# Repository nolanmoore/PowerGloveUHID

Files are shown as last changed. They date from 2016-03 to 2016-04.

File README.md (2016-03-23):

## Intro

In a world... where wires are a thing of the past, pound signs are now hashtags and there is always a “new black,” one man will revive a gaming icon in order to preserve the past… and control the future.

The ultimate goal of the Power Glove UHID (Universal Human Interface Device) project is to revamp the 1989 Nintendo Power Glove with modern sensors, giving you the ability to use gesture controls with almost anything you can think of, in style.

Check out the [Hackaday.io project page](https://hackaday.io/project/8455-power-glove-uhid) for more info!

## Revisions

### Main Board
* Rev 0.1 (current): Complete! Features custom keypad, Teensy 3/LC header, ESP-12E/01 headers and Pololu 3.3V step up/down regulator.<br />
Top side:<br />
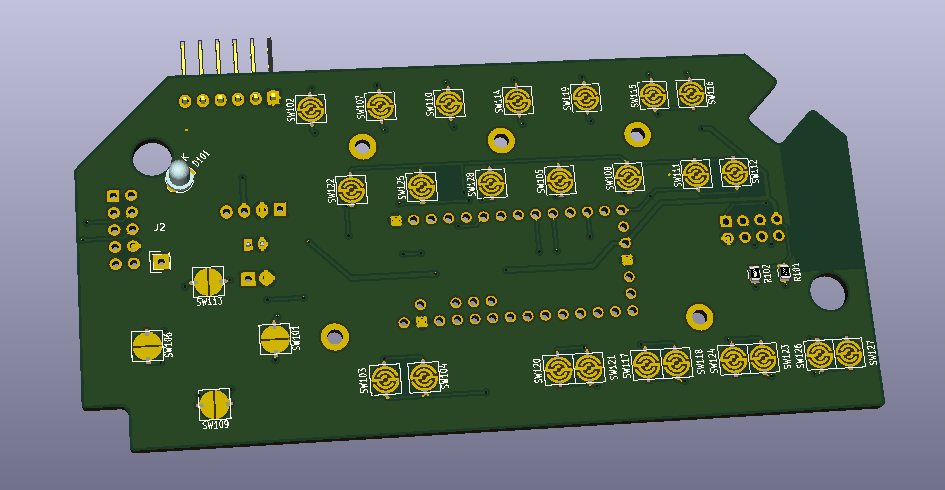
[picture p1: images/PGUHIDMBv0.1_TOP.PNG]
Power Glove UHID main board - top side
<br />
Bottom side:<br />
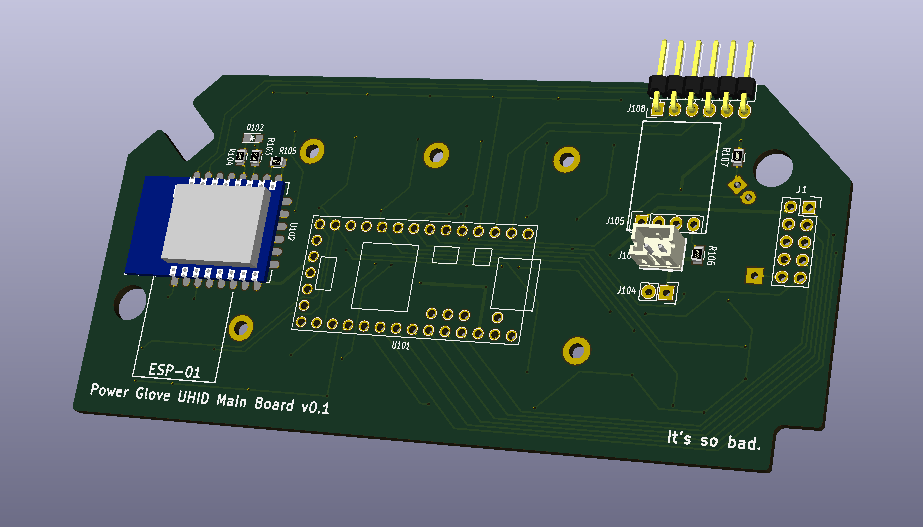
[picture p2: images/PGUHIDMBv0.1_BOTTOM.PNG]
Power Glove UHID main board - bottom side


### Sensor Board
* Rev 0.1 (current): Unfinished WIP. Along with the existing flex sensors, the current prototype sensor board will feature a Pololu AltIMU-10 as the main sensor.

## License

This is an open hardware design licensed under the terms of the CERN Open Hardware Licence (OHL) v1.2.

You may redistribute and modify this documentation under the terms of the CERN OHL v.1.2 (http://ohwr.org/cernohl). This documentation is distributed WITHOUT ANY EXPRESS OR IMPLIED WARRANTY, INCLUDING OF MERCHANTABILITY, SATISFACTORY QUALITY AND FITNESS FOR A PARTICULAR PURPOSE. Please see the CERN OHL v.1.2 for applicable conditions.

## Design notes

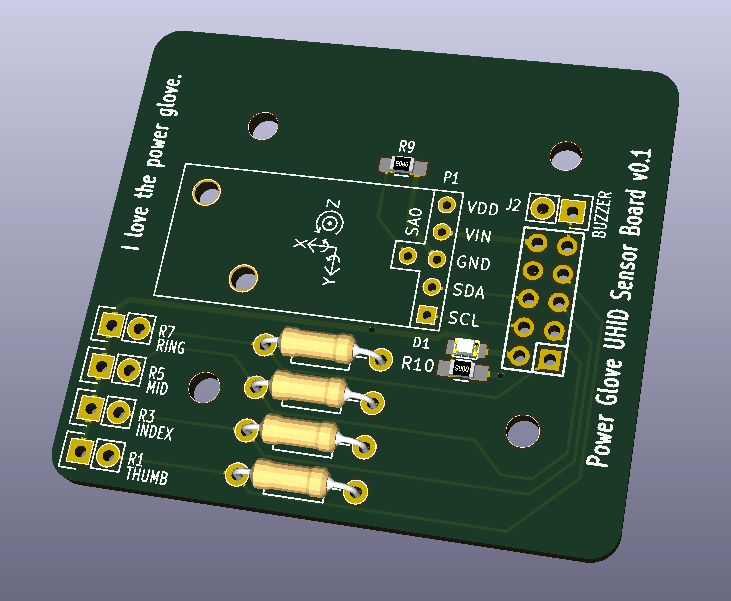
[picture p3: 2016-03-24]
images/PGUHIDSBv0.1_TOP.PNG

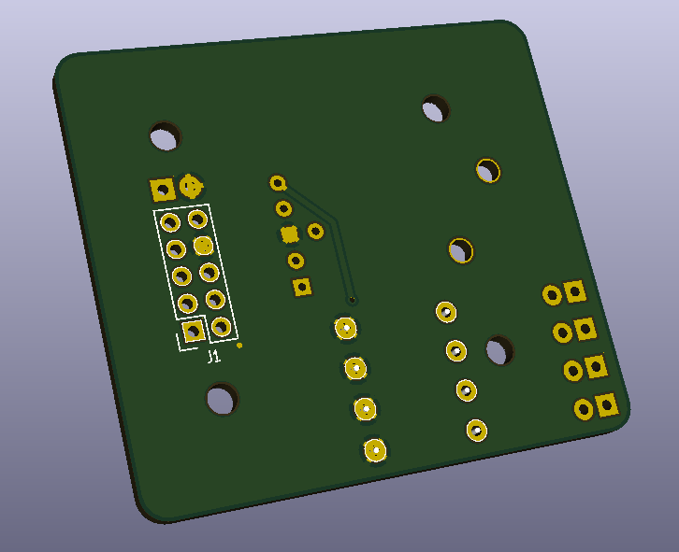
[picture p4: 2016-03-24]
images/PGUHIDSBv0.1_BOTTOM.PNG

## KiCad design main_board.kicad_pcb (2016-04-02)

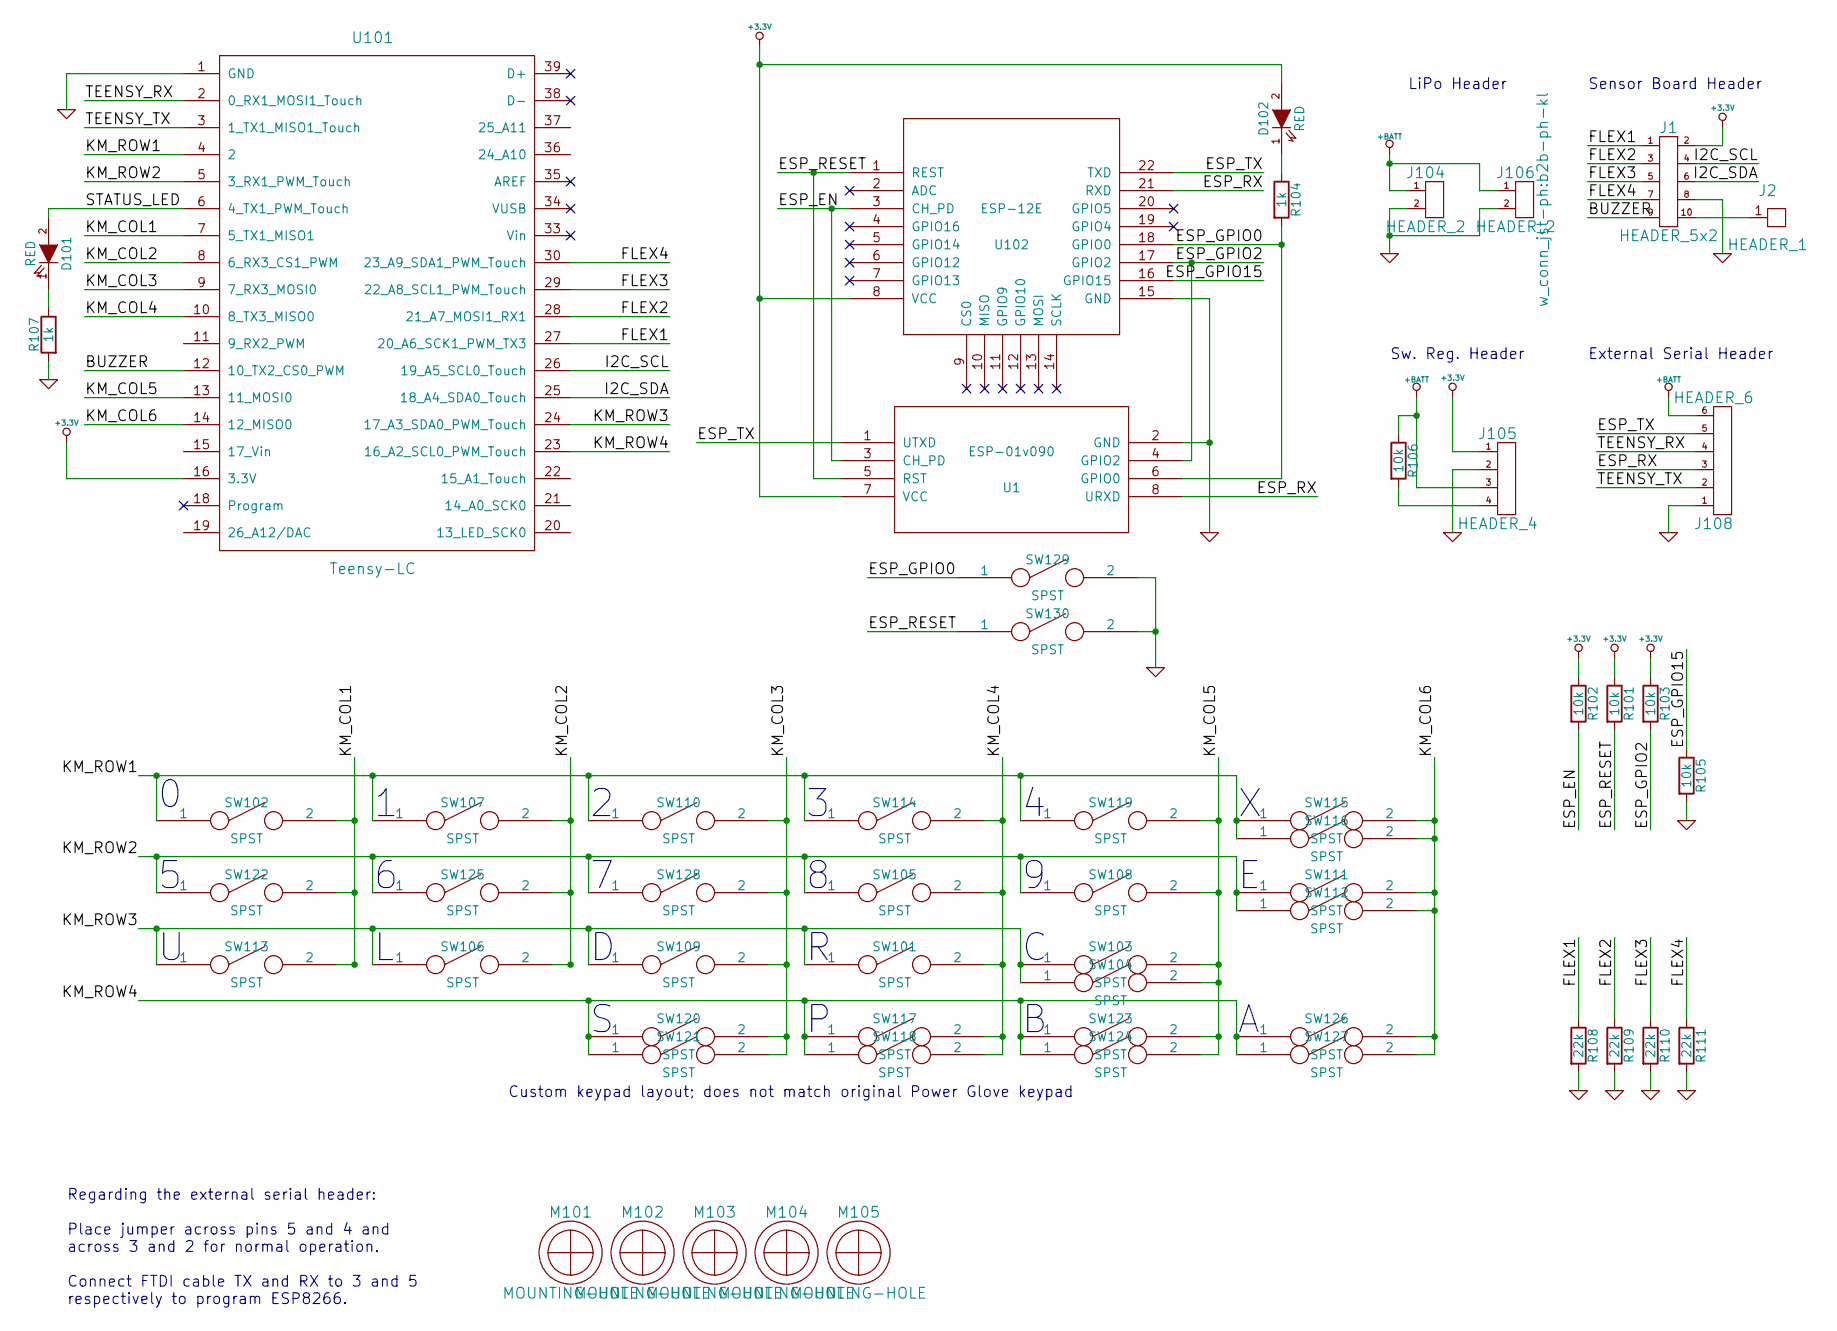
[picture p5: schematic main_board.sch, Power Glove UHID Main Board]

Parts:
D101: RED; LED-3MM
D102: RED; LED_0805
J1: HEADER_5x2; Socket_Strip_Straight_2x05
J2: HEADER_1; Socket_Strip_Straight_1x01
J104: HEADER_2; Socket_Strip_Straight_1x02
J105: HEADER_4; Socket_Strip_Straight_1x04
J106: HEADER_2; b2b-ph-kl
J108: HEADER_6; Pin_Header_Angled_1x06
M101, M102, M103, M104, M105: MOUNTING-HOLE; MountingHole_2-2mm
R101, R102, R103, R105, R106: 10k; R_0805
R104, R107: 1k; R_0805
R108, R109, R110, R111: 22k; R_0805
SW101, SW106, SW109, SW113: SPST; CONDUCTIVE-PAD-HALFSHELL-150MIL
SW102, SW103, SW104, SW105, SW107, SW108, SW110, SW111, SW112, SW114, SW115, SW116, SW117, SW118, SW119, SW120, SW121, SW122, SW123, SW124, SW125, SW126, SW127, SW128: SPST; CONDUCTIVE-PAD-STANDARD-150MIL
SW129, SW130: SPST; Socket_Strip_Straight_1x02
U1: ESP-01v090; ESP-01
U101: Teensy-LC; Teensy3.x_LC
U102: ESP-12E

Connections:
+3.3V: D102.2 (A), J1.2, J105.1, R101.1, R102.1, R103.1, U1.7 (VCC), U101.16 (3.3V), U101.31 (3.3V), U102.8 (VCC)
+BATT: J104.1, J105.3, J106.1, J108.6, R106.1
/BUZZER: J1.9, U101.12 (10_TX2_CS0_PWM)
/ESP_EN: R102.2, U1.3 (CH_PD), U102.3 (CH_PD)
/ESP_GPIO0: R104.2, SW129.1, U1.6 (GPIO0), U102.18 (GPIO0)
/ESP_GPIO2: R103.2, U1.4 (GPIO2), U102.17 (GPIO2)
/ESP_GPIO15: R105.1, U102.16 (GPIO15)
/ESP_RESET: R101.2, SW130.1, U1.5 (RST), U102.1 (REST)
/ESP_RX: J108.3, U1.8 (URXD), U102.21 (RXD)
/ESP_TX: J108.5, U1.1 (UTXD), U102.22 (TXD)
/FLEX1: J1.1, R108.1, U101.27 (20_A6_SCK1_PWM_TX3)
/FLEX2: J1.3, R109.1, U101.28 (21_A7_MOSI1_RX1)
/FLEX3: J1.5, R110.1, U101.29 (22_A8_SCL1_PWM_Touch)
/FLEX4: J1.7, R111.1, U101.30 (23_A9_SDA1_PWM_Touch)
/I2C_SCL: J1.4, U101.26 (19_A5_SCL0_Touch)
/I2C_SDA: J1.6, U101.25 (18_A4_SDA0_Touch)
/KM_COL1: SW102.2, SW113.2, SW122.2, U101.7 (5_TX1_MISO1)
/KM_COL2: SW106.2, SW107.2, SW125.2, U101.8 (6_RX3_CS1_PWM)
/KM_COL3: SW109.2, SW110.2, SW120.2, SW121.2, SW128.2, U101.9 (7_RX3_MOSI0)
/KM_COL4: SW101.2, SW105.2, SW114.2, SW117.2, SW118.2, U101.10 (8_TX3_MISO0)
/KM_COL5: SW103.2, SW104.2, SW108.2, SW119.2, SW123.2, SW124.2, U101.13 (11_MOSI0)
/KM_COL6: SW111.2, SW112.2, SW115.2, SW116.2, SW126.2, SW127.2, U101.14 (12_MISO0)
/KM_ROW1: SW102.1, SW107.1, SW110.1, SW114.1, SW115.1, SW116.1, SW119.1, U101.4 (2)
/KM_ROW2: SW105.1, SW108.1, SW111.1, SW112.1, SW122.1, SW125.1, SW128.1, U101.5 (3_RX1_PWM_Touch)
/KM_ROW3: SW101.1, SW103.1, SW104.1, SW106.1, SW109.1, SW113.1, U101.24 (17_A3_SDA0_PWM_Touch)
/KM_ROW4: SW117.1, SW118.1, SW120.1, SW121.1, SW123.1, SW124.1, SW126.1, SW127.1, U101.23 (16_A2_SCL0_PWM_Touch)
/STATUS_LED: D101.2 (A), U101.6 (4_TX1_PWM_Touch)
/TEENSY_RX: J108.4, U101.2 (0_RX1_MOSI1_Touch)
/TEENSY_TX: J108.2, U101.3 (1_TX1_MISO1_Touch)
GND: J1.8, J104.2, J105.2, J106.2, J108.1, R105.2, R107.2, R108.2, R109.2, R110.2, R111.2, SW129.2, SW130.2, U1.2 (GND), U101.1 (GND), U101.17 (GND), U101.32 (GND), U102.15 (GND)
unnamed: D101.1 (K), R107.1
unnamed: D102.1 (K), R104.1
unnamed: J1.10, J2.1
unnamed: J105.4, R106.2

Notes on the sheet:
Sensor Board Header
LiPo Header
Custom keypad layout; does not match original Power Glove keypad
External Serial Header
Regarding the external serial header: Place jumper across pins 5 and 4 and across 3 and 2 for normal operation. Connect FTDI cable TX and RX to 3 and 5 respectively to program ESP8266.
Sw. Reg. Header

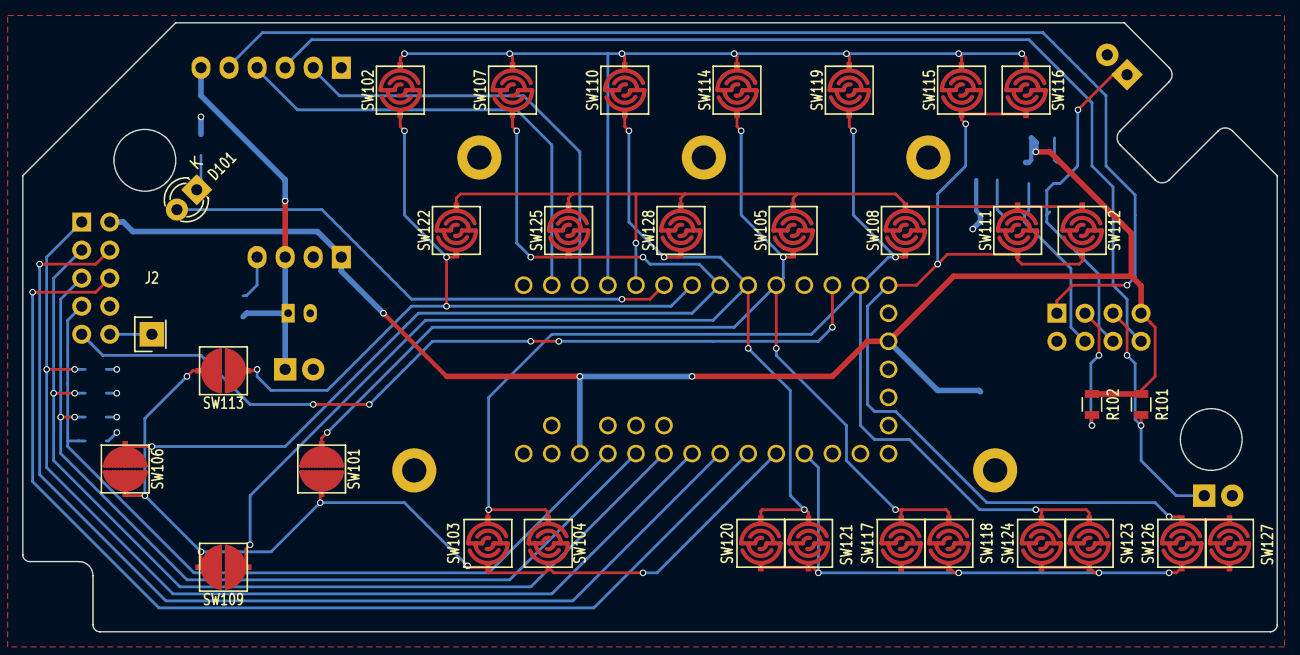
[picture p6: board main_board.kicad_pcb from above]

Board: 2 copper layers, 113.5 x 55.1 mm, 57 parts (0 on the bottom side), 34 nets.

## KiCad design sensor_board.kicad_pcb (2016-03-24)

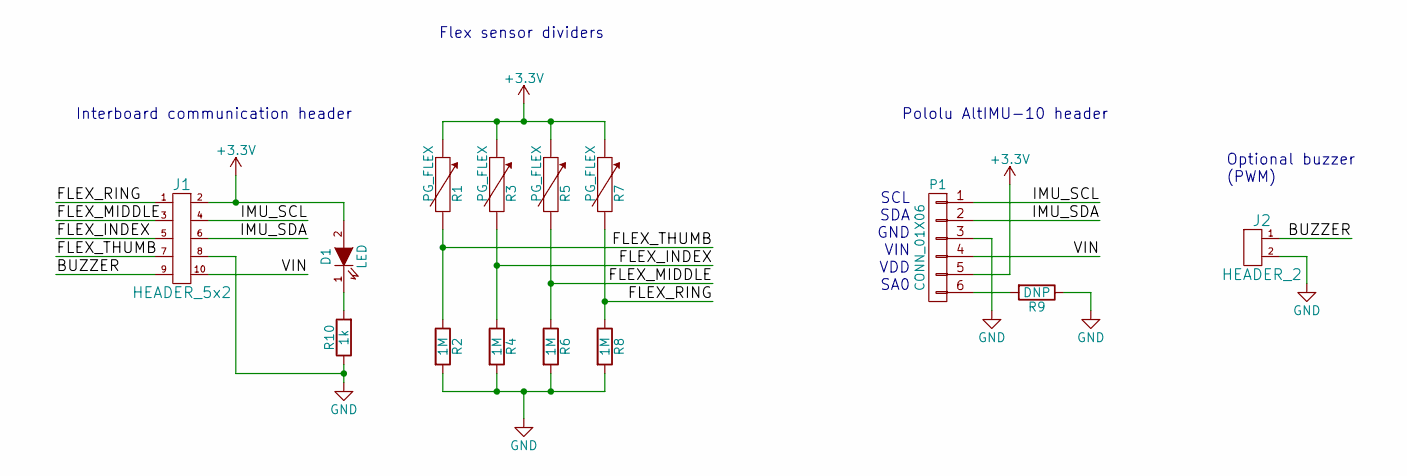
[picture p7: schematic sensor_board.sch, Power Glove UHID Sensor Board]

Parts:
D1: LED; Led_0805
J1: HEADER_5x2; Socket_Strip_Straight_2x05
J2: HEADER_2; Socket_Strip_Straight_1x02
P1: CONN_01X06; ALTIMU10
R1, R3, R5, R7: PG_FLEX; Socket_Strip_Straight_1x02
R2, R4, R6, R8: 1M; Resistor_Horizontal_RM10mm
R9: DNP; R_0805_HandSoldering
R10: 1k; R_0805_HandSoldering

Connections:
+3V3: D1.2 (A), J1.2, P1.5, R1.1, R3.1, R5.1, R7.1
/BUZZER: J1.9, J2.1
/FLEX_INDEX: J1.5, R3.2, R4.1
/FLEX_MIDDLE: J1.3, R5.2, R6.1
/FLEX_RING: J1.1, R7.2, R8.1
/FLEX_THUMB: J1.7, R1.2, R2.1
/IMU_SCL: J1.4, P1.1
/IMU_SDA: J1.6, P1.2
/VIN: J1.10, P1.4
GND: J1.8, J2.2, P1.3, R2.2, R4.2, R6.2, R8.2, R9.1, R10.1
unnamed: D1.1 (K), R10.2
unnamed: P1.6, R9.2

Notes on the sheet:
SCL SDA GND VIN VDD SA0
Flex sensor dividers
Interboard communication header
Pololu AltIMU-10 header
Optional buzzer (PWM)

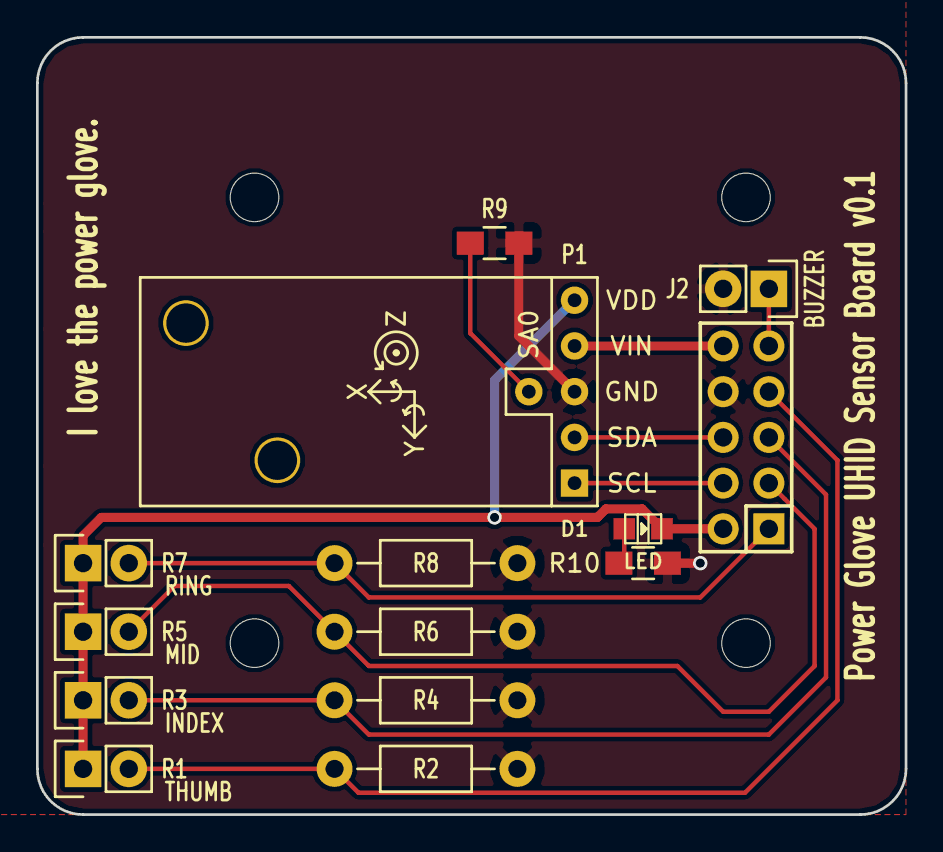
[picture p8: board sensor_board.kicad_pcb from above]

Board: 2 copper layers, 48.3 x 43.2 mm, 14 parts (1 on the bottom side), 12 nets.

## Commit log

2016-03-13 Initial upload, everything still WIP
    I do NOT advise you to send these to OSH just yet
    [main_board.kicad_pcb, main_board.sch, sensor_board.kicad_pcb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]
2016-03-21 Final main board v0.1
    Last big upload commit before I start doing proper commits ;)
    [main_board.kicad_pcb, main_board.sch]
2016-03-21 Cleaned up schematics and sensor board PCB
    [main_board.sch, sensor_board.kicad_pcb, sensor_board.sch]
2016-03-21 Readme update, added renders of current prototypes
2016-03-23 Sensor board revised fit within a 5cmX5cm square
    [sensor_board.kicad_pcb, sensor_board.sch]
2016-03-24 Rearranged sensor board components for cleanliness
    [main_board.kicad_pcb, sensor_board.kicad_pcb, sensor_board.sch]
2016-03-24 Sensor board images added, gerbers plotted
    [main_board-B.Mask.gbs, main_board-B.Paste.gbp, main_board-B.SilkS.gbo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]
2016-04-02 Bumped version to 0.2, cleaned schematic, added voltage divider resistors, boot and reset buttons
    [main_board.kicad_pcb, main_board.sch]
